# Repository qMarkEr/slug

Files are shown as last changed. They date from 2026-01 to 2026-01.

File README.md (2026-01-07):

# The multifunctional device to interact with your pc
and to collect the dust :) \
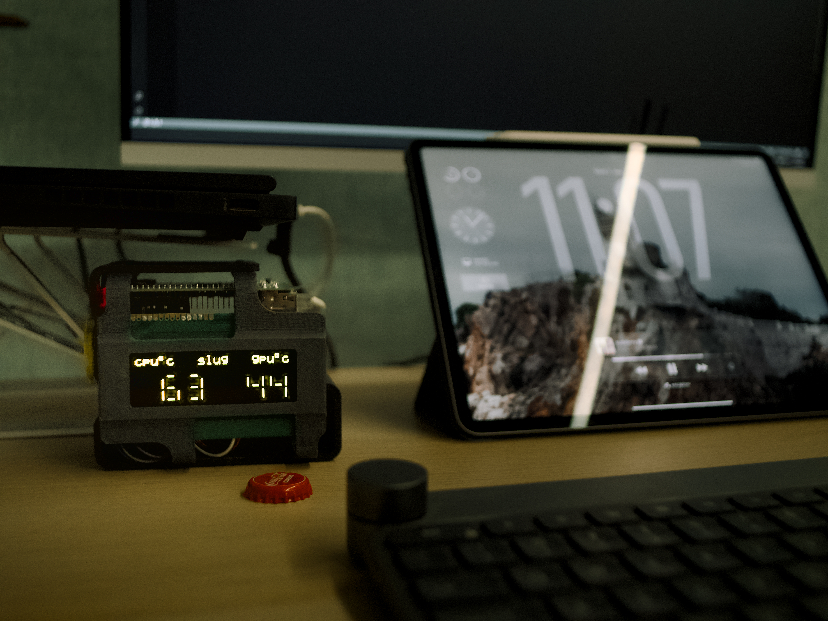
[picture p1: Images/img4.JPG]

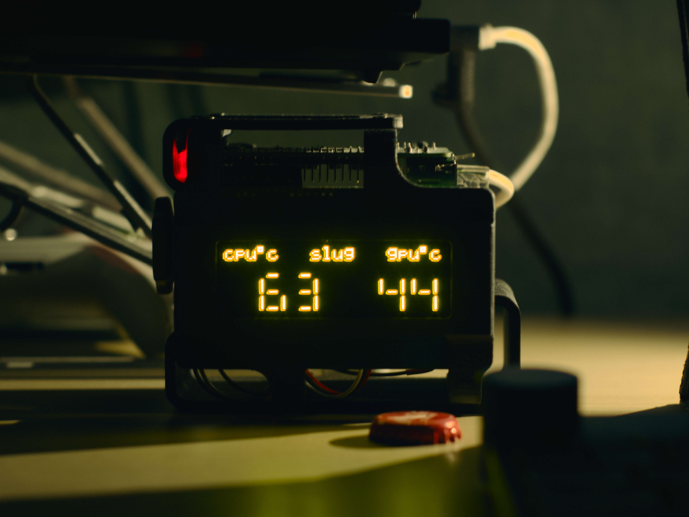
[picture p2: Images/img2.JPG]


# General Info

- This device was created for my own purposes
- All parts are designed by me and ready to print
- The valve rotation is encoded by the AS5600 chip
    - [AS5600 magnetic encoder datasheet](https://files.seeedstudio.com/wiki/Grove-12-bit-Magnetic-Rotary-Position-Sensor-AS5600/res/Magnetic%20Rotary%20Position%20Sensor%20AS5600%20Datasheet.pdf)
- When the mode is changed the vibration motor gives you a tactile feedback
- The screen is 20x4 WS0010-based char display from Winstar
    - [Display link](https://www.winstar.com.tw/products/oled-module/oled-character-display/20x4-oled.html)
    - [WS0010 datasheet](https://cdn-shop.adafruit.com/datasheets/WS0010.pdf)

# Interaction

- The switch to turn on the PC and put it to the sleep mode\
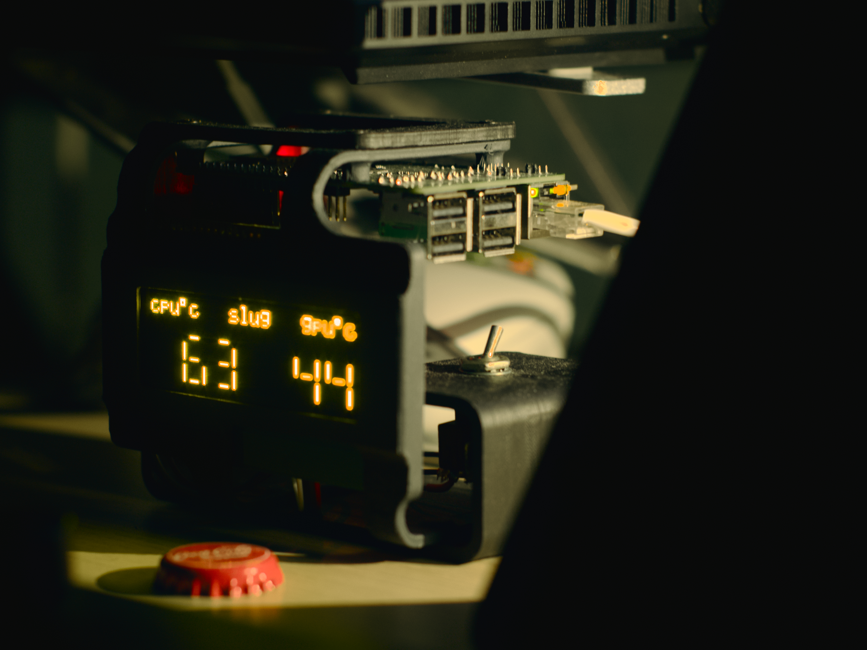
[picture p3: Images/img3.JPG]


- The valve to choose the mode of the device\
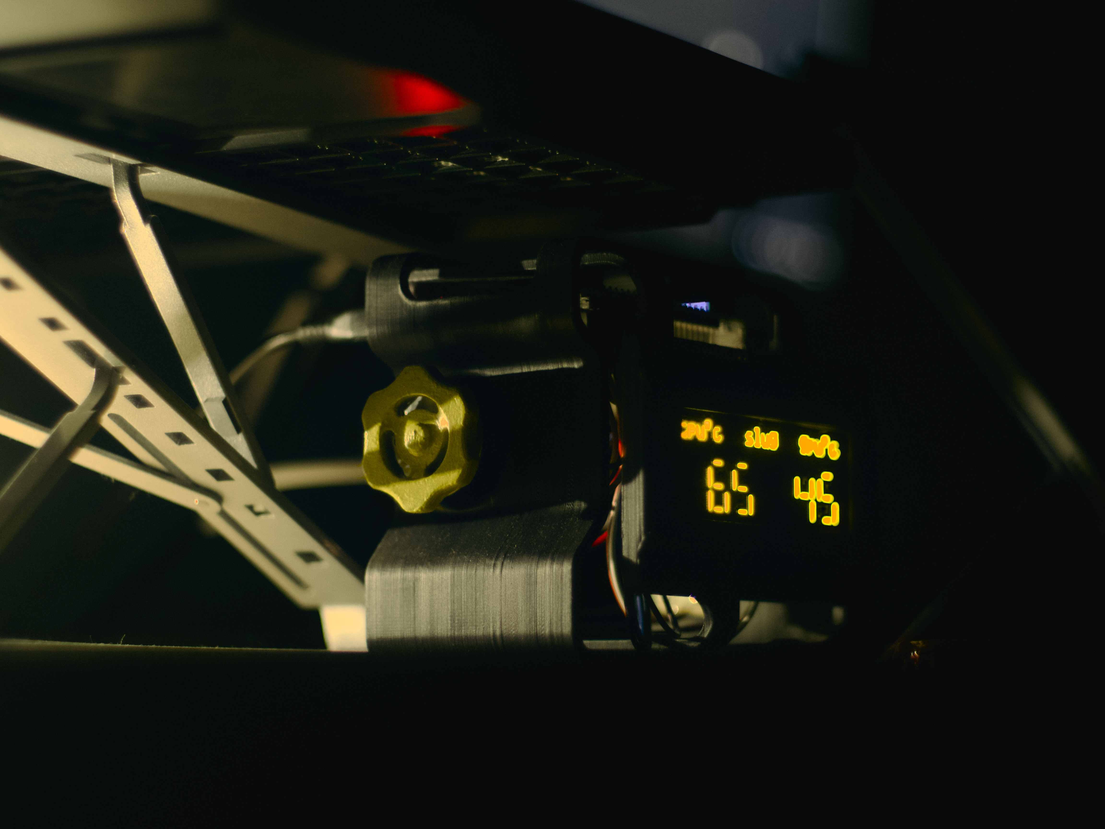
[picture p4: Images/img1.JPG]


## Currently available modes
- gambling (kinda like a slot machine)
- Temperature monitor for the PC
- Clock
- Screensaver like the DVD logo
- nothing

# How does it work?
- The main PC hosts the ASP.NET app that can put it into sleep and sends the json with CPU/GPU temperatures via http
- The RPi hosts a client service that
    -  wakes PC using WOL packet
    -  requests the temps from the API to show them on the screen

# Setup

## Part 0. Wiring

* AS5600:
    * SDA -> GPIO2
    * SCL -> GPIO3
    * VCC -> 3.3 V
    * GND -> GND
    * DIR -> GND

* Vibration motor
    * VCC -> 5V (or 3.3V if you wnat it to be more gentle)
    * GND -> GND
    * IN -> GPIO10

* Screen
    * 1 GND -> GND
    * 2 VCC -> 5V
    * 3 NC -> _
    * 4 RS -> GPIO14
    * 5 R/W -> GND
    * 6 E -> GPIO15
    * 7 DB0 -> _
    * 8 DB1 -> _
    * 9 DB2 -> _
    * 10 DB3 -> _
    * 11 DB4 -> GPIO18
    * 12 DB5 -> GPIO23
    * 13 DB6 -> GPIO24
    * 14 DB7 -> GPIO25
    * 15 NC -> _
    * 16 NC -> _

You can do your own wiring, but in that case you need to change the GPIO numbers in the `main.c` and the `hotslug.h`

## Part 1. PC
### Prerequisites

* .NET SDK installed (e.g., .NET 6/7/8)
* An ASP.NET Core project
* Administrator/root privileges (required to create services)

Check your SDK:

```pwsh
dotnet --version
```

---

### 1. Build the Project (Release Mode)

From the repository root:

```bash
cd Server
dotnet build -c Release
```

### 2. Publish the Project

```pwsh
dotnet publish -c Release -o ./publish
```

### 3. Create a Windows Service (Windows)

#### 3.1 Copy files

Copy the contents of the `publish` folder to a permanent location, e.g.:

```
C:\Services\MyAspNetApp
```

#### 3.2 Create the service

Run **PowerShell as Administrator**:

```pwsh
New-Service \
  -Name "MyAspNetApp" \
  -BinaryPathName "C:\Services\MyAspNetApp\MyAspNetApp.exe" \
  -DisplayName "My ASP.NET Core App" \
  -StartupType Automatic
```

### 3.3 Start the service

```powershell
Start-Service MyAspNetApp
```

### 3.4 Check status

```powershell
Get-Service MyAspNetApp
```

Logs are typically written to Windows Event Viewer or application-specific log files.

## Part 2. Raspberry Pi

### Prerequisites

* Raspberry Pi OS (Debian-based)
* CMake-based C or C++ project
* Root (sudo) access

### Required packages

```bash
sudo apt update
sudo apt install -y \
  build-essential \
  cmake \
  pigpio \
  libcurl4-openssl-dev \
  libcjson-dev
```

```bash
sudo systemctl enable pigpiod
sudo systemctl start pigpiod
```

### 1. Copy files
* Copy **Client** and **util** folders to any location on your RPi
* Create permanent folder
```bash
sudo mkdir /var/www
sudo mkdir /var/www/hotslug
```
### 2. Build the project
In the `Client` folder run:
```bash
mkdir -p build
cd build
cmake  ..
sudo make
```
Optional: test the binary locally
```bash
sudo bash /var/www/hotslug/hotslug
```

### 3. Create the service

* Navigate to the util directory
* Run
```bash
sudo ./link_service.sh
```

### 4. Change the IP and MAC in hotslug.h

```C
22 #define WAKE_UP "sudo etherwake <YOUR MAC>"
23 #define SLEEP_DOWN "curl -X POST http://<YOUR IP>:5221/api/control/sleep"
24 #define TEMPS  "http://<YOUR IP>:5221/api/temps"
```

# 3D-models
* main-case.stl \
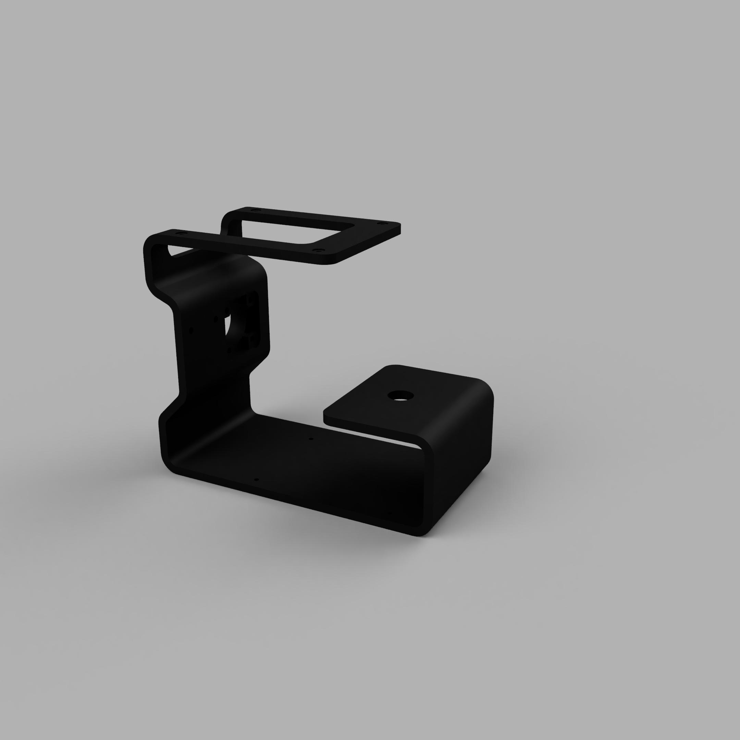
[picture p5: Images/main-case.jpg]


* rpi-and-screen-mount.stl \
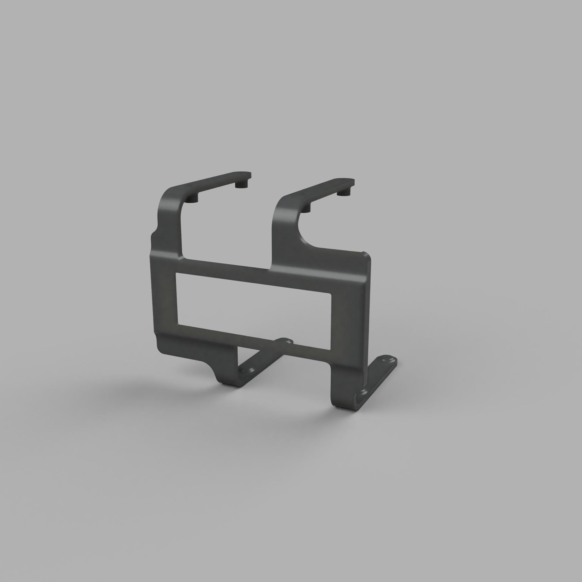
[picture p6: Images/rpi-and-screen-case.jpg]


* valve.stl \
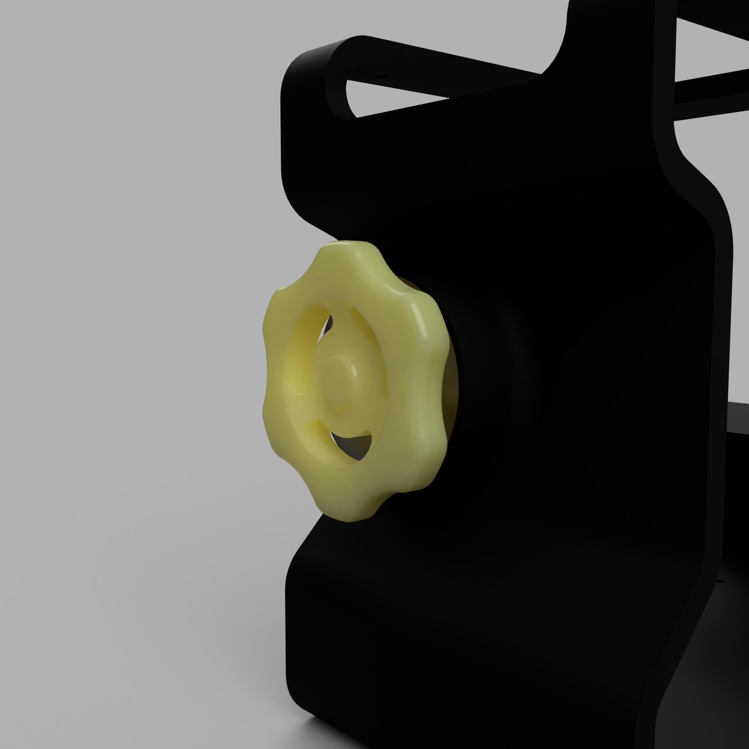
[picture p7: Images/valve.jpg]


# Yapping

- feel free to use
- feel free to contribute

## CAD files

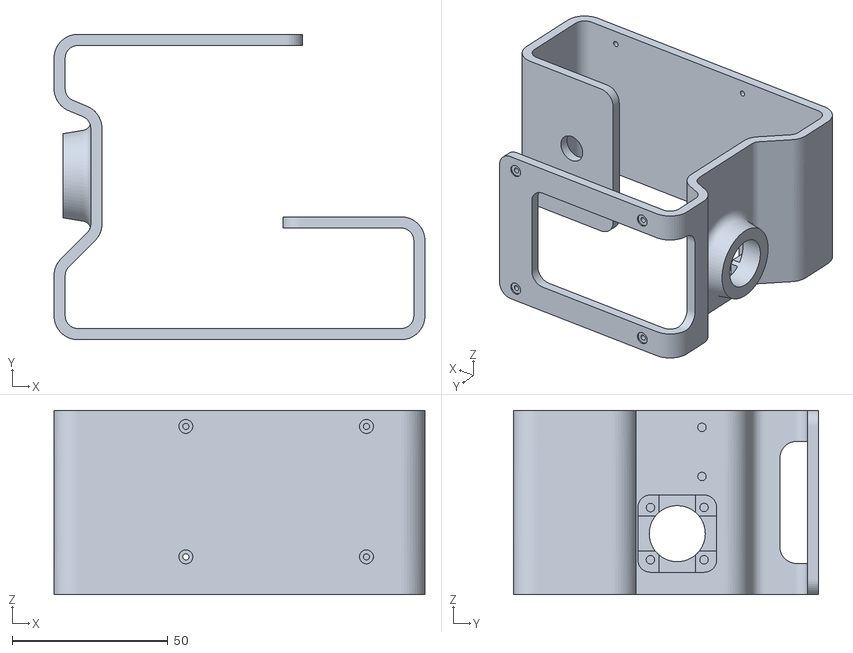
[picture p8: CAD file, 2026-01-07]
Housing models/main-case.stl
119.1 x 98.1 x 59.2

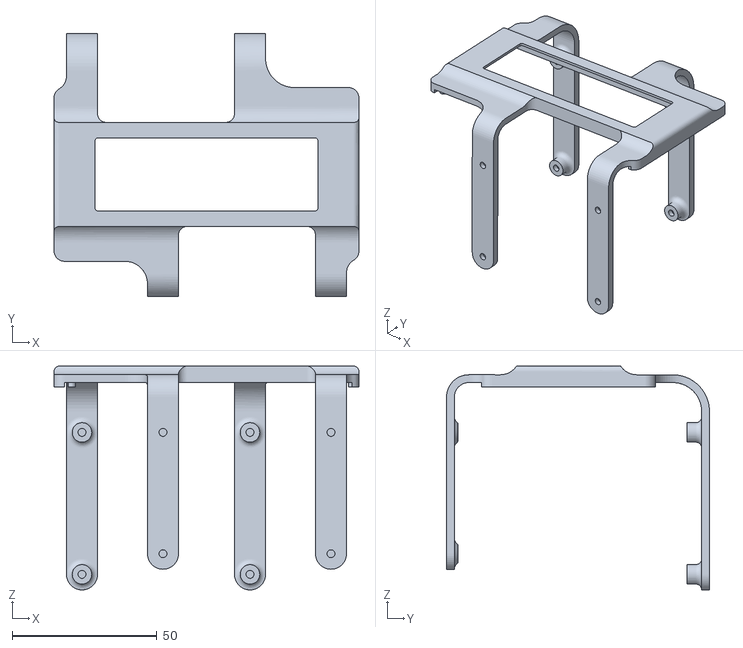
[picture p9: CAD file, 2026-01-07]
Housing models/rpi-and-screen-mount.stl
105.3 x 90.8 x 77.3

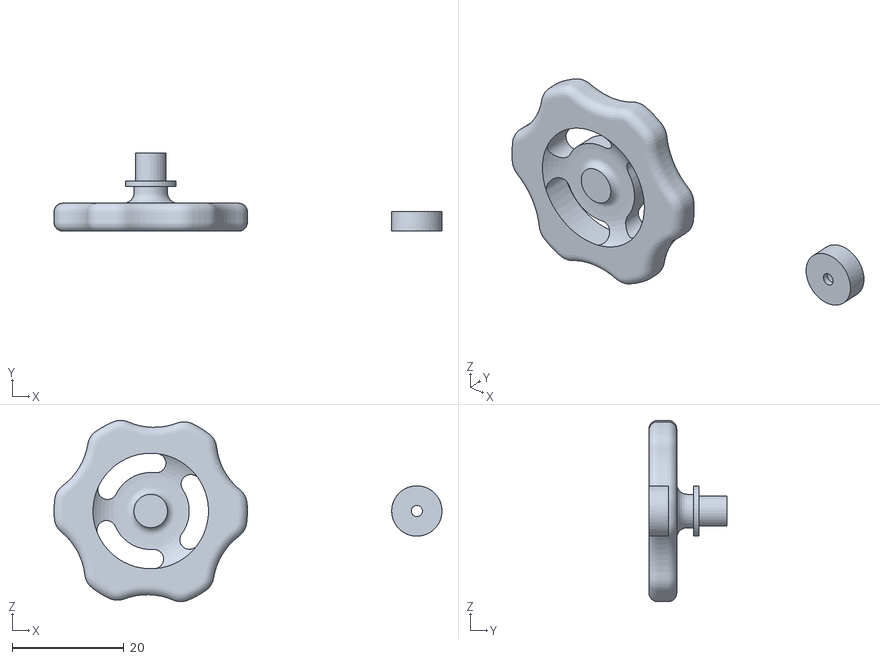
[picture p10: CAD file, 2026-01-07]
Housing models/valve.stl
69.3 x 14.0 x 32.4

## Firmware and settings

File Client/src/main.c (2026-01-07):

#include "slug.h"
#include <stdint.h>

static uint64_t state = 0x853c49e6748fea9bULL;
static uint64_t inc   = 0xda3e39cb94b95bdbULL;

uint32_t pcg32(void) {
    uint64_t oldstate = state;
    state = oldstate * 6364136223846793005ULL + (inc | 1);
    uint32_t xorshifted = ((oldstate >> 18u) ^ oldstate) >> 27u;
    uint32_t rot = oldstate >> 59u;
    return (xorshifted >> rot) | (xorshifted << ((-rot) & 31));
}

int rand_range(int min, int max) {
    return min + (int)(pcg32() % (max - min + 1));
}
// signal handle
volatile sig_atomic_t done = 0;
void term(int signum) { done = 1; }

// mutex
volatile int input_flag = 1;
pthread_mutex_t display_lock = PTHREAD_MUTEX_INITIALIZER;

// utils
int read_angle(int h) {
    int lo = i2cReadByteData(h, 0x0F);
    int hi = i2cReadByteData(h, 0x0E) << 8;
    return  hi | lo;
}

int clamp(int val, int rest) { return (rest + val) % rest; }

void interruptable_sleep(int seconds) {
    for (int i = 0; i < (seconds * 10) && !input_flag; i++)
        usleep(100000);
}

void *mode_thread(void *arg)
{
    WorkerArgs* args = (WorkerArgs*)arg;
    int mode = args->mode;
    WEH002004A* display = args->display;
    free(args);

    pthread_mutex_lock(&display_lock);
    display_clear(display);
    switch (mode)
    {
        case 0: // temps
            while (!input_flag)
            {
                int cpu, gpu;
                char lines[3][LINE_SIZE] = {};
                int code = get_cpu_gpu_stats(&cpu, &gpu);
                if (code && gpioRead(BUTTON_PIN)) {
                    display_write_line(display, 0, "cpu\xDF""c   slug   gpu\xDF""c");
                    write_temps(cpu, gpu, lines);
                    for (size_t i = 0; i < 3; i++)
                        display_write_line(display, i + 1, lines[i]);
                    interruptable_sleep(1);
                        
                } else {
                    int i = 0;
                    while (i < 60 && !input_flag && !gpioRead(BUTTON_PIN)) {
                        screensaver(display);
                        interruptable_sleep(5);
                        i += 5;
                    }
                }
            }
            break;
        case 1: // time
            while (!input_flag)
            {
                char lines[3][LINE_SIZE] = {};
                display_write_line(display, 0, "time     to     goon");
                write_time(lines);
                for (size_t i = 0; i < 3; i++)
                    display_write_line(display, i + 1, lines[i]);
                interruptable_sleep(60);
            }
            break;
        case 2: // display off
            display_clear(display);
            break;
        case 3: // screensaver
            uint8_t x = 0;
            uint8_t y = 0;
            uint8_t x_dir = 1;
            uint8_t y_dir = 1;
            while (!input_flag)
            {
                display_write_word(display, y, x, "    ");
                
                if (x == 0) x_dir = 1;
                else if (x > 14) x_dir = -1;
                if (y == 0) y_dir = 1;
                else if (y == 3) y_dir = -1;
                
                x += x_dir * 2;
                y += y_dir;

                display_write_word(display, y, x, "slug");
                interruptable_sleep(1);
            }
            break;
        case 4:
            int comb[3] = {
                rand_range(0, 6),
                rand_range(0, 6),
                rand_range(0, 6)
            };
            char lines[4][LINE_SIZE] = {};
            print_icons(comb, lines);
            if (comb[0] == comb[1] && comb[1]  == comb[2]) {
                for (size_t i = 0; i < 4; i++)
                    display_write_line(display, i, lines[i]);
                vibrate_request_signal();
                usleep(500000);
                display_clear(display);
                usleep(500000);
                for (size_t i = 0; i < 4; i++)
                    display_write_line(display, i, lines[i]);
                vibrate_request_signal();
                usleep(500000);
                display_clear(display);
                usleep(500000);
                vibrate_request_signal();
            }
            for (size_t i = 0; i < 4; i++)
                display_write_line(display, i, lines[i]);
            break;
        default:
            break;
    }
    pthread_mutex_unlock(&display_lock);
    return NULL;
}


int main() {
    // init
    if (gpioInitialise() < 0) {
        printf("pigpio failed.\n");
        return 1;
    }
    
    int h = i2cOpen(1, AS5600_ADDR, 0);
    if (h < 0)
    {
        printf("Cannot open I2C device\n");
        return 1;
    }

    struct sigaction action;
	memset(&action, 0, sizeof(struct sigaction));
	action.sa_handler = term;
	sigaction(SIGTERM, &action, NULL);
	sigaction(SIGINT, &action, NULL);
	sigaction(SIGTSTP, &action, NULL);

    WEH002004A display = {
        .RS = 14, .E = 15,
        .data_pins = {18, 23, 24, 25},

        .E_PULSE = 2e-6,
        .E_DELAY = 2e-6,
        .CMD_DELAY_SHORT = 0.0001,
        .CMD_DELAY_LONG = 0.002,
        .WRITE_LINE_WIDTH = 20
    };

    display_initialize(&display);
    setup_button(BUTTON_PIN);
    setup_vibe();
    pthread_t tid;
    pthread_create(&tid, NULL, vibe_thread, NULL);

    int mode = 1;
    int inc = 1;
    uint16_t prev_angle = read_angle(h);
    uint16_t abs_pos = prev_angle;
    char preview[7];
    const char* modes[] = {"slug", "goon", "offw", "scsv", "gamb"};

    // main loop
    while (!done)
    {
        uint16_t angle = read_angle(h);
        int movement = angle - prev_angle;

        if (abs(movement) > 16) {
            if (!input_flag)
            {
                display_clear(&display);
                snprintf(preview, sizeof(preview), "-%s-", modes[mode]);
                display_write_word(&display, 0, 8, modes[clamp(mode + 1, MODE_COUNT)]);
                display_write_word(&display, 1, 7, preview);
                display_write_word(&display, 2, 8, modes[clamp(mode - 1, MODE_COUNT)]);
            }
            input_flag = 1;

            int direction = movement > 0;
            uint16_t delta = clamp(angle - abs_pos, 4096);
            if (abs(movement) >= 2048) direction = !direction;

            if ((delta / 512) % 2 == 1) inc = 0;
            if ((delta / 512) % 2 == 0 && !inc) {
                inc = 1;
                vibrate_request_signal();
                mode = clamp(mode + (direction ? 1 : -1), MODE_COUNT);
                snprintf(preview, sizeof(preview), "-%s-", modes[mode]);
                display_write_word(&display, 0, 8, modes[clamp(mode + 1, MODE_COUNT)]);
                display_write_word(&display, 1, 7, preview);
                display_write_word(&display, 2, 8, modes[clamp(mode - 1, MODE_COUNT)]);
            }

            prev_angle = angle;
        } else {
            if (input_flag) {
                inc = 1;
                WorkerArgs *args = malloc(sizeof(WorkerArgs));
                args->mode = clamp(mode, MODE_COUNT);
                args->display = &display;
                pthread_t mode_thrd;
                pthread_create(&mode_thrd, NULL, mode_thread, args);
                pthread_detach(mode_thrd);
            }
            input_flag = 0;
            abs_pos = prev_angle;
        }
        usleep(100000);
    }

    // clear
    display_clear(&display);
    display_write_line(&display, 0, "Не поминайте лихом!");
    sleep(1);
    display_power(&display, 0);
    i2cClose(h);
    gpioTerminate();

    return 0;
}

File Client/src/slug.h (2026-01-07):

#ifndef SLUGGGG
#define SLUGGGG

#include <stdio.h>
#include <string.h>
#include <pigpio.h>
#include <unistd.h>
#include <pthread.h>
#include <stdlib.h>
#include <signal.h>
#include <time.h>
#include <curl/curl.h>
#include <cjson/cJSON.h>
#include <stdint.h>

#define BUTTON_PIN 10
#define VIBRO_PIN 4
#define VIBE_DURATION_MS 200

#define AS5600_ADDR 0x36
#define DEBOUNCE_MS 50
#define WAKE_UP "sudo etherwake BC:0F:F3:D8:72:63"
#define SLEEP_DOWN "curl -X POST http://192.168.0.60:5221/api/control/sleep"
#define TEMPS  "http://192.168.0.60:5221/api/temps"
#define MODE_COUNT 5
#define LINE_SIZE 21

static const char *ICONS[7][4] = {
    {
        " __ ",
        "   |",
        "  / ",
        " |  "
    },  // 7
    {
        " __ ",
        "|  |",
        "|__|",
        " __ "
    },  // ciclop
    {
        "    ",
        "()()",
        " __ ",
        "    "
    },  // ciclop
    {
        "    ",
        "  6 ",
        " 7  ",
        "    "
    },  // sixeven
    {
        " -- ",
        " == ",
        " __ ",
        " == "
    },  // barcode
    {
        "   /",
        "  / ",
        " /  ",
        "/   "
    },  // giga slash
    {
        "(__)",
        "(__)",
        "(__)",
        "(__)"
    },  // spine bone sory 4 my bad england
};

static const char *BIG_DIGIT[10][3] = {
    {
        " _ ",
        "| |",
        "|_|"
    },  // 0
    {
        "   ",
        "  |",
        "  |"
    },  // 1
    {
        " _ ",
        " _|",
        "|_ "
    },  // 2
    {
        " _ ",
        " _|",
        " _|"
    },  // 3
    {
        "   ",
        "|_|",
        "  |"
    },  // 4
    {
        " _ ",
        "|_ ",
        " _|"
    },  // 5
    {
        " _ ",
        "|_ ",
        "|_|"
    },  // 6
    {
        " _ ",
        "  |",
        "  |"
    },  // 7
    {
        " _ ",
        "|_|",
        "|_|"
    },  // 8
    {
        " _ ",
        "|_|",
        " _|"
    }   // 9
};

typedef struct {
    int RS, E;
    int data_pins[4];

    // timing
    double E_PULSE;
    double E_DELAY;
    double CMD_DELAY_SHORT;
    double CMD_DELAY_LONG;

    int WRITE_LINE_WIDTH;
} WEH002004A;

typedef enum {
    TASK_WAKE,
    TASK_SLEEP
} TaskType;

typedef struct {
    int mode;
    WEH002004A* display;
} WorkerArgs;

// digits
void write_temps(int cput, int gput, char out[3][21]);
void write_time(char out[3][LINE_SIZE]);
void print_icons(int set[3], char out[4][LINE_SIZE]);

// winstar WEH2004A
void display_initialize(WEH002004A *display);
void display_write_line(WEH002004A *display, int line, const char *msg);
void display_write_word(WEH002004A *display, int row, int col, const char *msg);
void display_clear(WEH002004A *display);
void display_power(WEH002004A *display, int on);

// wake up / sleep down
void button_watchdog(int gpio, int level, uint32_t tick);
void setup_button(unsigned int pin);

// og hotslug
void screensaver(WEH002004A* display);
int get_cpu_gpu_stats(int *cpu_out, int *gpu_out);

// vibration (vibe)
void *vibe_thread(void *arg);
void vibrate_request_signal();
void setup_vibe();
// gfx mode test
// static inline void gfx_select_x(WEH002004A* display, uint8_t x);
// static inline void gfx_select_bank(WEH002004A* display, uint8_t bank);
// static void gfx_write_col(WEH002004A* display, uint8_t x, uint8_t bank, uint8_t value);
// void gfx_set_pixel(WEH002004A* display, int x, int y, int on);
// void gfx_flush_all(WEH002004A* display);
// void gfx_clear(WEH002004A* display);
// void set_gfx_mode(WEH002004A* display);

#endif
